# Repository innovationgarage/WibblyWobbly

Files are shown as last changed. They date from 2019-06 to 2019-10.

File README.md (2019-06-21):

# Wibbly Wobbly
Tiny data collector based on a ESP8266

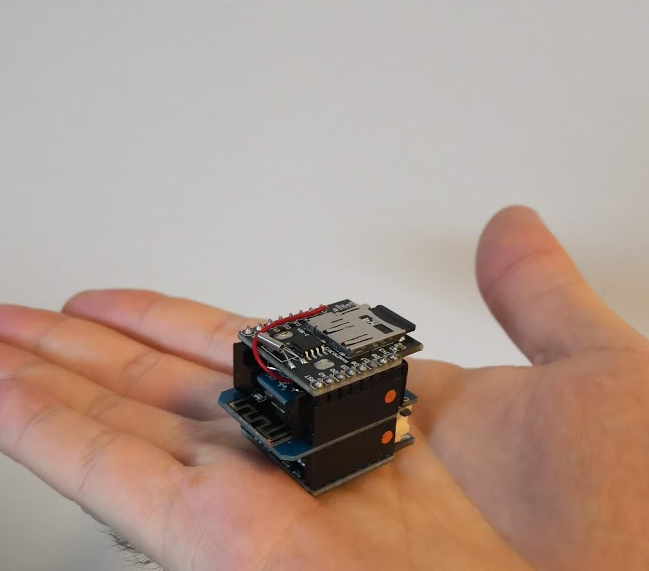
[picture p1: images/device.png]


# Parts

* Wemos D1 https://www.aliexpress.com/item/10pcs-D1-PRO-Battery-Shield-D1-mini-Mini-NodeMcu-4M-bytes-Lua-WIFI-Internet-of-Things/32832670731.html
* Battery shield https://www.aliexpress.com/item/D1-Mini-Battery-Shield-Lithium-Battery-Charging-Boost-With-LED-Light-Module-Mini-Micro-USB-Interface/32798209192.html
* RTC SD shield https://www.aliexpress.com/item/RTC-DS1307-Real-Time-Clock-DataLog-Shield-for-Micro-SD-WeMos-D1-Mini-RTC-DS1307-Clock/32839371626.html
* Accelerometer/Gyro GY-521 https://www.aliexpress.com/item/MPU-6050-3-Axis-gyroscope-acce-lerometer-module-3V-5V-compatible-For-Arduino/2035920870.html

# Assembly

## Layout stack

    SD/RTC Shield
    --------------
    Accel/Gyro module held by hardware/gyro_holder.stl (x2, 1 mirrored)
    --------------
    Wemos D1
    --------------
    Battery shield
    
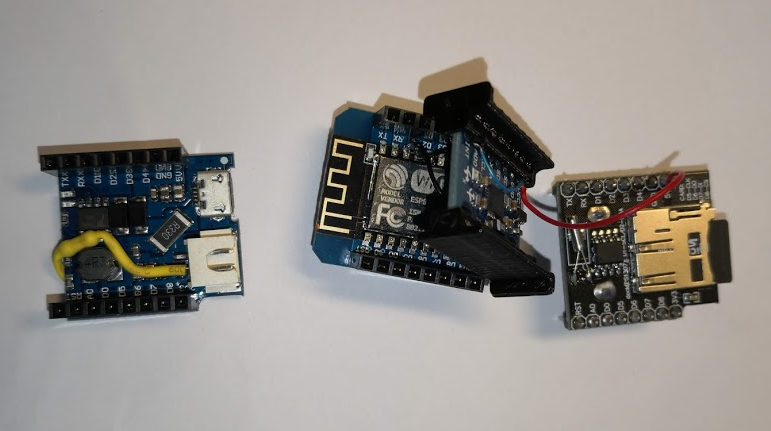
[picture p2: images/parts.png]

    
## Connections

Accel/Gyro module: 5V and GND should be connected to the respective rail. SCL to D1, SDA to D2 and AD0 to 5V.

Battery shield: Bridge A0 to batt+ with a 100 ohm resistor.

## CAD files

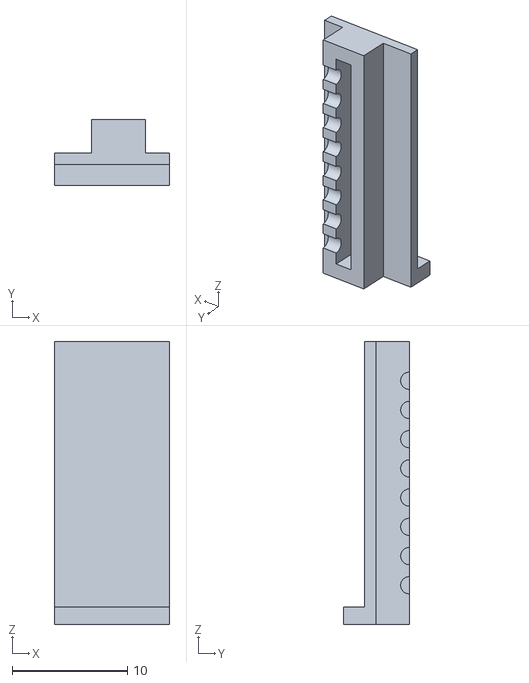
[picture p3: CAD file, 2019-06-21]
hardware/gyro_holder.stl
10.0 x 5.70 x 24.6

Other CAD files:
hardware/gyro_holder.ipt

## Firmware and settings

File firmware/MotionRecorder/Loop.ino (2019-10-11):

unsigned long wait;

bool wifiEnabled = WIFI_ENABLED;
unsigned long timeoutWifiAccess = 0;

void loop() {
  if (wifiEnabled && millis() < timeoutWifiAccess)
  {
    server.handleClient();
    MDNS.update();
  }
  else
  {
    if (wifiEnabled)
    {
      // Disable wifi
      DBG_OUTPUT_PORT.print("Checking if nobody is actually connected");

      if (wifi_softap_get_station_num() == 0)
      {
        DBG_OUTPUT_PORT.print("Turning WiFi access point off...");
        WiFi.softAPdisconnect(true);
        WiFi.enableAP(false);
        wifiEnabled = false;
      }
      else
        timeoutWifiAccess = millis() + TIMEOUT_WIFI;
    }
    else
    {
      // Do SD data collection
      // Create the output file
      String filename = String("capture_");
      filename += random(100000, 999999);
      filename += ".txt";

      String d = String("time,diff_ms,ax,ay,az,gx,gy,gz,temp,batt");
      DBG_OUTPUT_PORT.println(filename);

      delay(5000);
      unsigned long startup = millis();
      while (true)
      {
        if (millis() > wait)
        {
          //DBG_OUTPUT_PORT.println("inside");

          File file = SD.open(filename, FILE_WRITE);
          if (file)
          {
            file.println(d);
            file.close();
            digitalWrite(D4, (millis() % 1000) > 500);
          }
          else
          {
            DBG_OUTPUT_PORT.println("error opening file");
          }
          //DBG_OUTPUT_PORT.println("outside");

          // Dump next one
          Read_RawValue(MPU6050SlaveAddress, MPU6050_REGISTER_ACCEL_XOUT_H);
          d = String(",");
          d += String(AccelX);
          d += String(",");
          d += String(AccelY);
          d += String(",");
          d += String(AccelZ);
          d += String(",");
          d += String(GyroX);
          d += String(",");
          d += String(GyroY);
          d += String(",");
          d += String(GyroZ);
          d += String(",");
          d += String(Temperature);
          d += String(",");
          d += String(analogRead(A0));

          String d2 = String(millis());
          d2 += ",";

          int time_it_took = (millis() - startup);
          startup = millis();

          d2 += time_it_took;
          d = d2 + d;

          wait = millis() + (70 - time_it_took);

          //DBG_OUTPUT_PORT.println("outside4");
          //DBG_OUTPUT_PORT.println(wait);
        }
      }
    }

  }
}

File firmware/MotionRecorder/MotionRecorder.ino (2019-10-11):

#include <Wire.h>
#include <SPI.h>
#include <SD.h>
#include <ESP8266WiFi.h>
#include <WiFiClient.h>
#include <ESP8266WebServer.h>
#include <ESP8266mDNS.h>
#include <RtcDS1307.h>

// -------------------- GENERAL -------------------------------
#define DBG_OUTPUT_PORT Serial

// -------------------- WIFI ----------------------------------
const bool WIFI_ENABLED = false; // Initialize wifi in the beggining
const int TIMEOUT_WIFI = 30000; // Ms to timeout wifi if there is no activity

#ifndef STASSID
#define STASSID "Wibbly Wobbly"
#endif

const char* ssid = STASSID;
const char* host = "wibblywobbly";

ESP8266WebServer server(80);

// -------------------- SD ------------------------------------
// change this to match your SD shield or module;
// WeMos Micro SD Shield V1.0.0: D8
// LOLIN Micro SD Shield V1.2.0: D4 (Default)
const int chipSelect = D4;

// -------------------- ACCELEROMETER/GYRO --------------------
// MPU6050 Slave Device Address
const uint8_t MPU6050SlaveAddress = 0x69;

// sensitivity scale factor respective to full scale setting provided in datasheet
const uint16_t AccelScaleFactor = 16384;
const uint16_t GyroScaleFactor = 131;

// MPU6050 few configuration register addresses
const uint8_t MPU6050_REGISTER_SMPLRT_DIV   =  0x19;
const uint8_t MPU6050_REGISTER_USER_CTRL    =  0x6A;
const uint8_t MPU6050_REGISTER_PWR_MGMT_1   =  0x6B;
const uint8_t MPU6050_REGISTER_PWR_MGMT_2   =  0x6C;
const uint8_t MPU6050_REGISTER_CONFIG       =  0x1A;
const uint8_t MPU6050_REGISTER_GYRO_CONFIG  =  0x1B;
const uint8_t MPU6050_REGISTER_ACCEL_CONFIG =  0x1C;
const uint8_t MPU6050_REGISTER_FIFO_EN      =  0x23;
const uint8_t MPU6050_REGISTER_INT_ENABLE   =  0x38;
const uint8_t MPU6050_REGISTER_ACCEL_XOUT_H =  0x3B;
const uint8_t MPU6050_REGISTER_SIGNAL_PATH_RESET  = 0x68;

int16_t AccelX, AccelY, AccelZ, Temperature, GyroX, GyroY, GyroZ;
//float Ax, Ay, Az, T, Gx, Gy, Gz;

// -------------------- RTC ------------------------------------
RtcDS1307<TwoWire> Rtc(Wire);
#define countof(a) (sizeof(a) / sizeof(a[0]))

void printDateTime(const RtcDateTime& dt)
{
  char datestring[20];

  snprintf_P(datestring,
             countof(datestring),
             PSTR("%02u/%02u/%04u %02u:%02u:%02u"),
             dt.Month(),
             dt.Day(),
             dt.Year(),
             dt.Hour(),
             dt.Minute(),
             dt.Second() );
  DBG_OUTPUT_PORT.print(datestring);
}
